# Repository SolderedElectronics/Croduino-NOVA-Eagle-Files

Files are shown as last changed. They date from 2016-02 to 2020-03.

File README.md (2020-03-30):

# Croduino NOVA Open Source Hardware Files
Croduino NOVA image
Buy Croduino NOVA [here](https://e-radionica.com/en/croduino-nova.html).

## Description and details
Croduino NOVA is microcontroller board capable of connecting to WiFi Internet network, made in Croatia(EU). It is based on very popular ESP8266 which is struggle to use standalone. With NOVA, just plug the board into USB port and start programming your next Internet-connected project(IoT)! Besides that, the board fits perfectly into a breadboard so prototyping is even more simple. Connecting the physical world to internet was never easier.

The braing of NOVA is ESP8266 produced by Espressif. It comes with complete WiFi(client and server side) and integrated TCP/IP stack which supports DNS. The most important thing - it is programmable from Arduino, there is even no need to manually reset the board due to auto-reset circuit onboard. It works at 80MHz frequency, has 1MB of flash for your code(of which 0.8MB available to you) and 82kB of RAM memory(of which 49kB available to you). NOVA also supports I2C, SPI and serial communication, there is 9 GPIO for you of which all support PWM and 1 analog input. Additionally, there is onboard: CP2102 USB to UART bridge (used for USB communication), 3.3V voltage regulator, 4 LEDs, it has FCC and CE certificate etc. In detail:

- ESP8266 in ESP-12 package
- 80MHz, 1MB flash, 82kB RAM
- programmable from Arduina!
- 9 GPIO pins of which all support PWM
- 1 analog input(ADC), max. voltage 1V i 5V
- I2C, SPI, serial communication
- CP2102 USB to UART bridge with micro USB connector
- 3.3V voltage regulator
- LEDs: power, tx, rx, GPIO13
- automatical hardware reset before upload of code
- two pushbuttons: reset i GPIO0
- comes with micro USB cable
- FCC i CE certificates for ESP-12

ESP8266 on-board is loaded with default bootloader.

## Repository content
This repo contains Cadsoft Eagle .sch and .brd files for the board. It also contains schematic in .pdf created from .sch Eagle file. 
Files have been arranged into folders for navigating between different versions of board. 
Tip: layer 200 shows top silkscreen and layer 208 is the bottom silkscreen. tParts and bParts layers are not used.

## Docs
- [Croduino NOVA product page](https://e-radionica.com/en/croduino-nova.html)

## Board versions
- v1.0 - inital published version 
- v1.1 - there was error near GPIO1 pushbutton in which GPIO0 was always directly connected to gnd. Fixed now. Silkscreen text is also a bit bigger and more readable.
- v1.2 - slight redesign, board longer 5mm and wider 2.54mm, added battery charger, changed LDO, parts rearranged. 

## License info
This product is [Open Source Hardware](https://en.wikipedia.org/wiki/Open-source_hardware), yay! Feel free to use it for any purpose you wish, but if you are ever in [Osijek, Croatia](https://goo.gl/maps/tEC2jWnBXJQpk9RJ7), you owe us a beer.

For any tech questions, please write on our [forum](http://forum.e-radionica.com/en/). If you find an Issue, please open one at GitHub. If you can improve our product, fork us.

e-radionica.com logo (https://e-radionica.com)

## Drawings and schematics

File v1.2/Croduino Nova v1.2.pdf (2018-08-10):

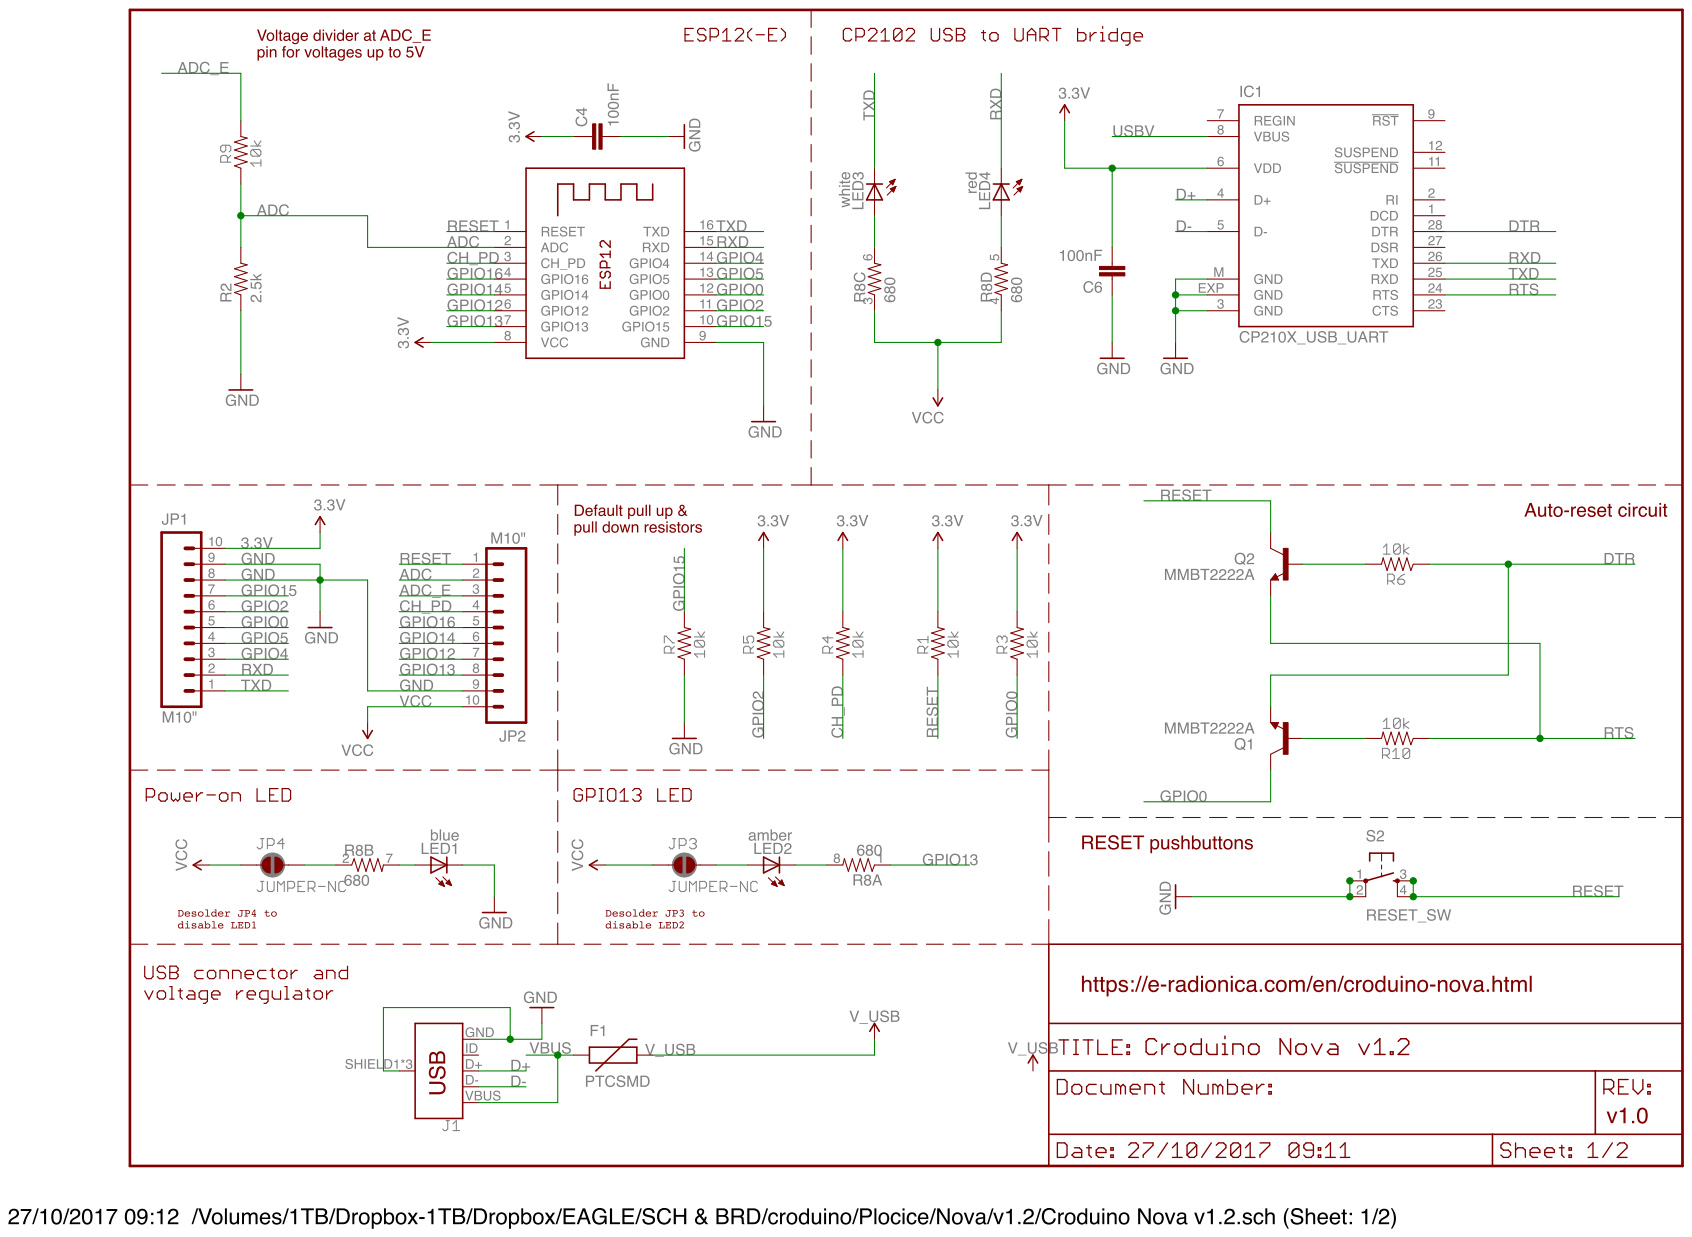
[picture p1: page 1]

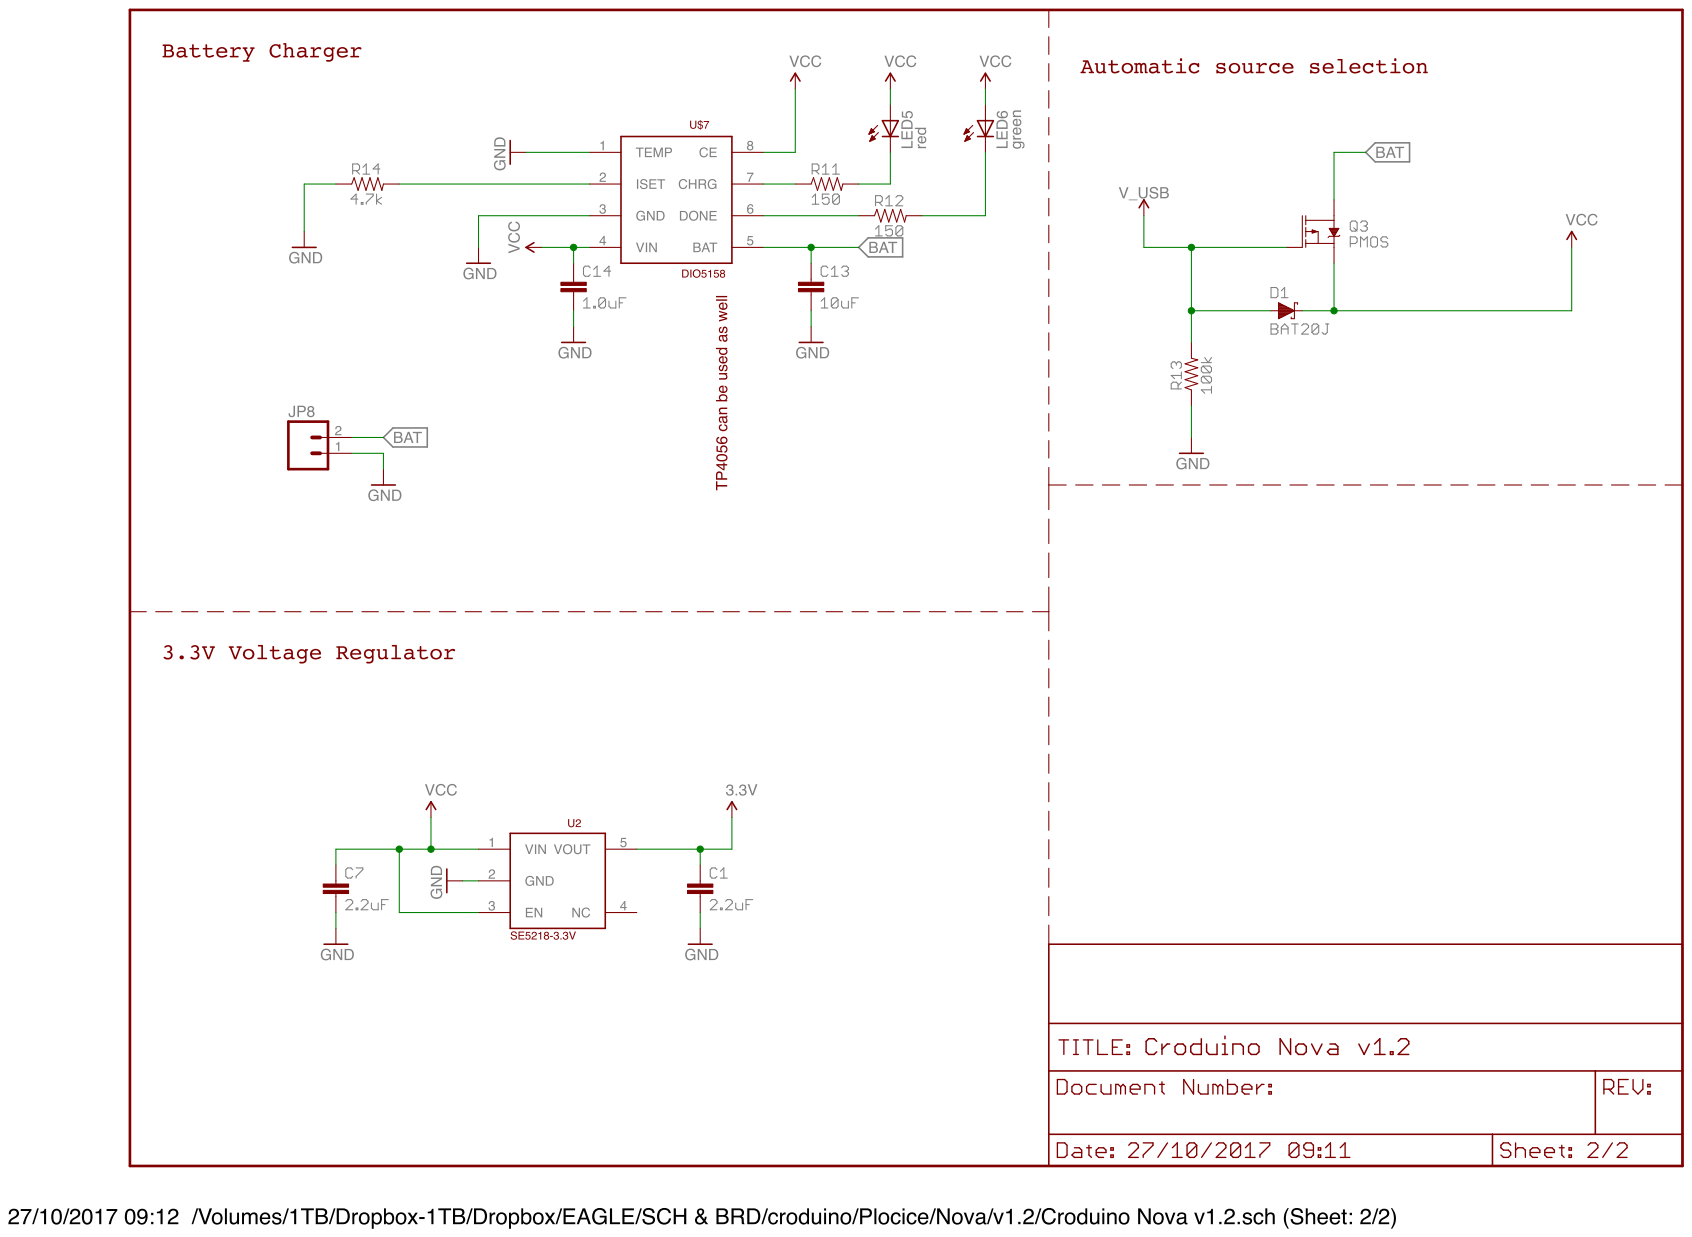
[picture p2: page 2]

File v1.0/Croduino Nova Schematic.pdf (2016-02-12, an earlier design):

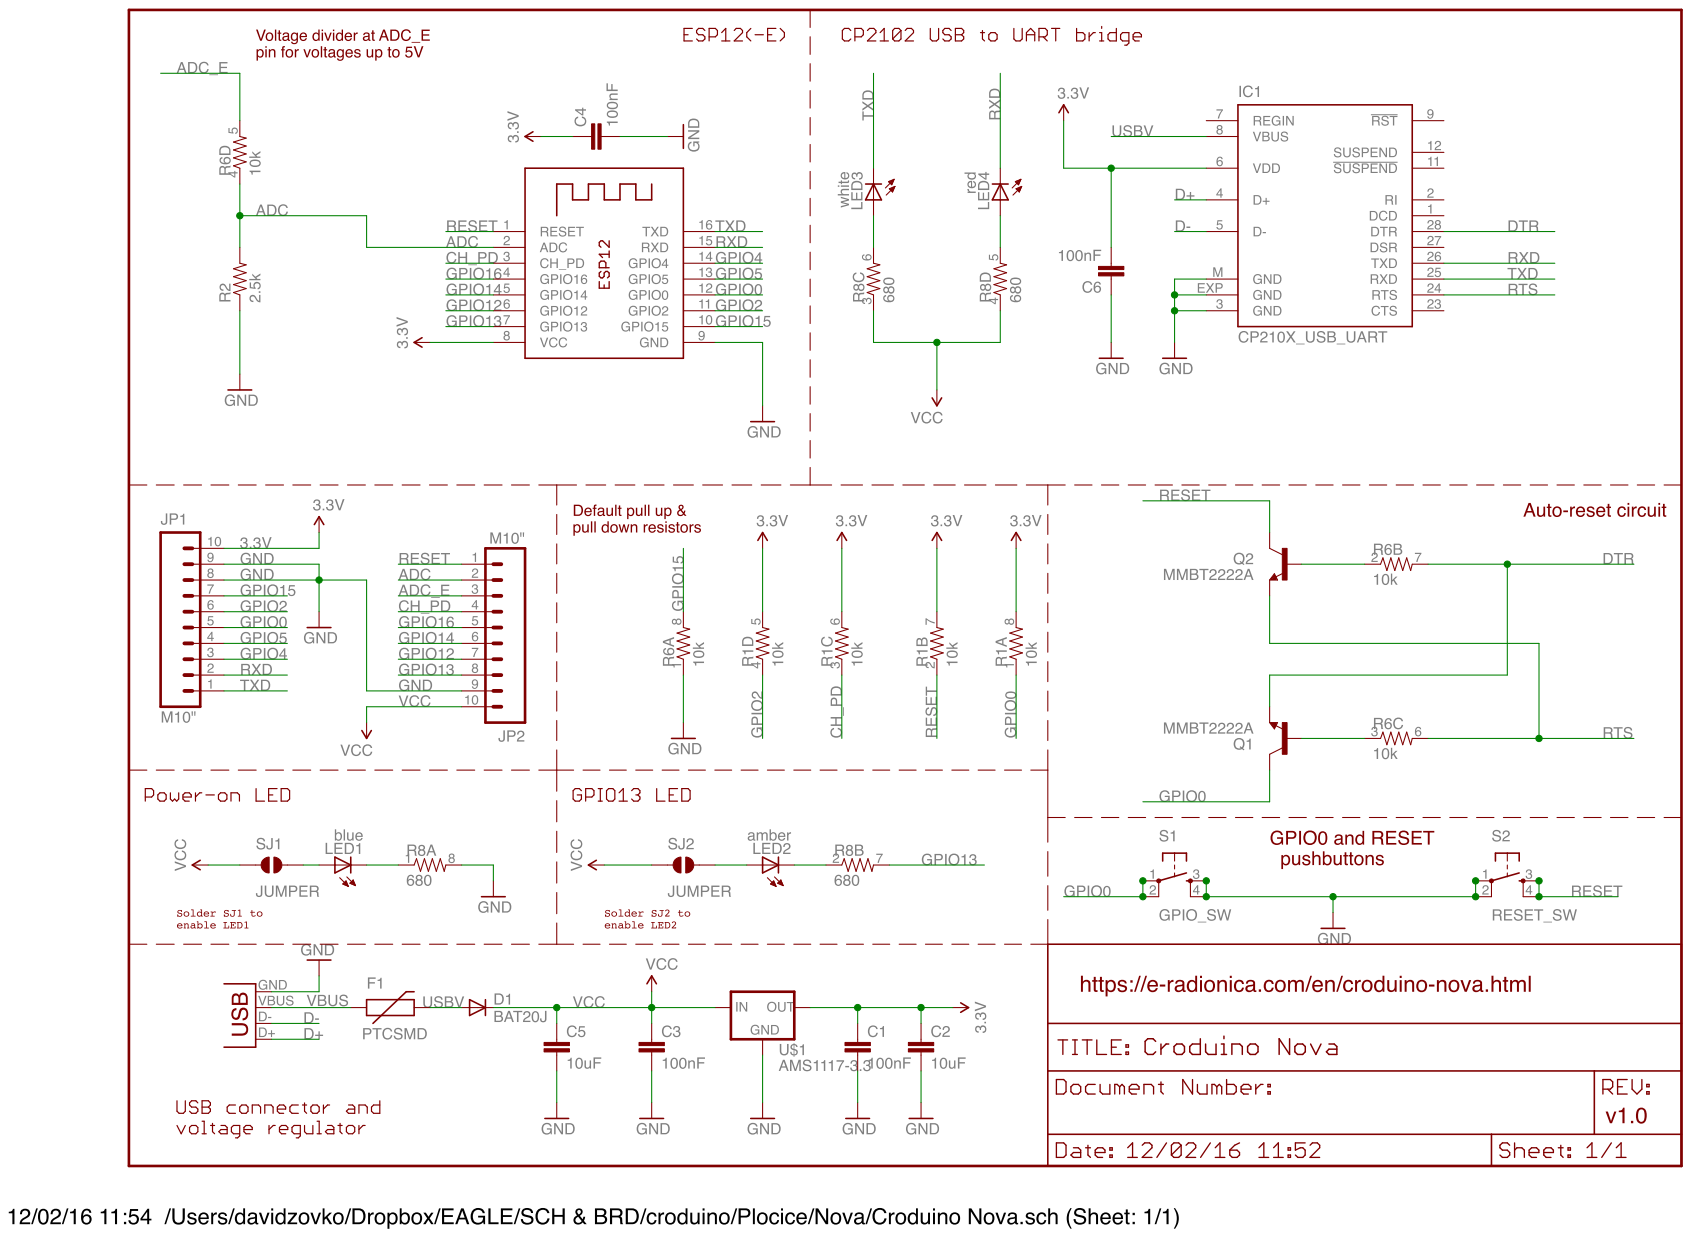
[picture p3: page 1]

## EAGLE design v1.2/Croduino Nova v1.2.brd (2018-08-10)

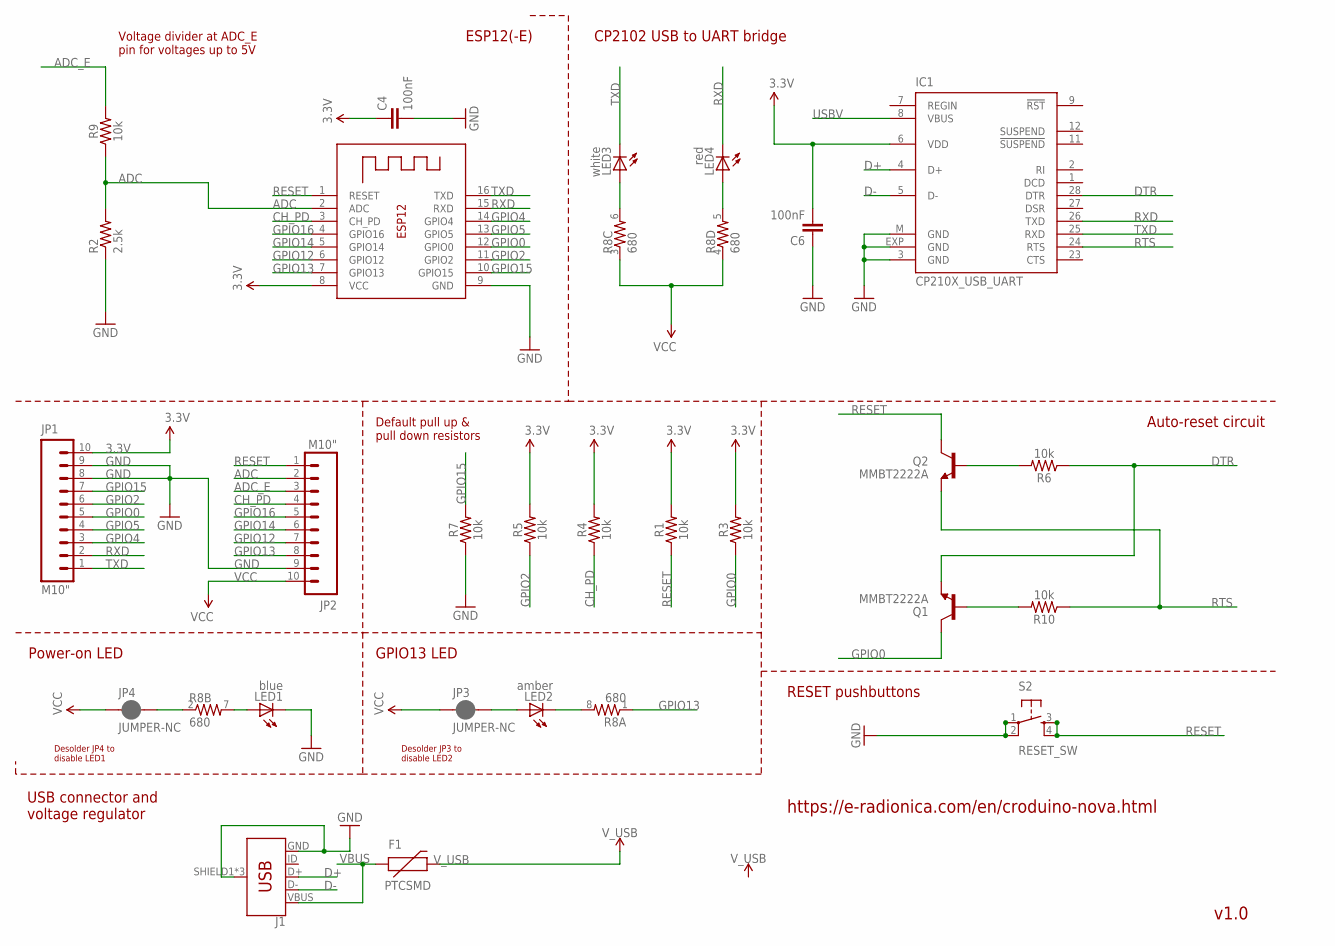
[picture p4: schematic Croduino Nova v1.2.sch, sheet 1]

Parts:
C4, C6: 100nF; 0603-CAP
F1: PTCSMD; PTC-1206
IC1: CP210X_USB_UART; MLP28
J1: USB_MICRO-BREDUCED_PASTE; USB-B-MICRO-SMD_RED_PASTE
JP1, JP2: M10"; 1X10
JP3, JP4: JUMPER-NC; SMT-JUMPER_2_NC_PASTE_NO-SILK
LED1: blue; CHIP-LED0805
LED2: amber; CHIP-LED0805
LED3: white; CHIP-LED0805
LED4: red; CHIP-LED0805
Q1, Q2: MMBT2222A; SOT23-3
R1, R3, R4, R5, R6, R7, R9, R10: 10k; 0603
R2: 2.5k; 0603-RES
R8: 680; 0603-ARV
S2: RESET_SW; TACTILE_SWITCH_SMD
X1: ESP8266-12; ESP-12

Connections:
3.3V: C4.1, C6.2, IC1.6 (VDD), JP1.10, R1.2, R3.2, R4.2, R5.2, X1.8 (VCC); also elsewhere on the board
ADC: JP2.2, R2.2, R9.1, X1.2 (ADC)
ADC_E: JP2.3, R9.2
CH_PD: JP2.4, R4.1, X1.3 (CH_PD)
D+: IC1.4 (D+), J1.D+
D-: IC1.5 (D-), J1.D-
DTR: IC1.28 (DTR), Q1.2 (E), R6.1
GND: C4.2, C6.1, IC1.3 (GND), IC1.EXP (GND), IC1.M (GND), J1.GND, J1.SHIELD1 (SHIELD), J1.SHIELD2 (SHIELD), J1.SHIELD3 (SHIELD), JP1.8, JP1.9, JP2.9, LED1.C, R2.1, R7.1, S2.1, S2.2, X1.9 (GND); also elsewhere on the board
GPIO0: JP1.5, Q1.3 (C), R3.1, X1.12 (GPIO0)
GPIO2: JP1.6, R5.1, X1.11 (GPIO2)
GPIO4: JP1.3, X1.14 (GPIO4)
GPIO5: JP1.4, X1.13 (GPIO5)
GPIO12: JP2.7, X1.6 (GPIO12)
GPIO13: JP2.8, R8.1, X1.7 (GPIO13)
GPIO14: JP2.6, X1.5 (GPIO14)
GPIO15: JP1.7, R7.2, X1.10 (GPIO15)
GPIO16: JP2.5, X1.4 (GPIO16)
unnamed: LED3.A, R8.6 (2)
unnamed: JP4.2, R8.2 (1)
unnamed: LED1.A, R8.7 (2)
unnamed: LED4.A, R8.5 (2)
unnamed: LED2.C, R8.8 (2)
unnamed: JP3.2, LED2.A
unnamed: Q1.1 (B), R10.2
unnamed: Q2.1 (B), R6.2
RESET: JP2.1, Q2.3 (C), R1.1, S2.3, S2.4, X1.1 (RESET)
RTS: IC1.24 (RTS), Q2.2 (E), R10.1
RXD: IC1.26 (TXD), JP1.2, LED4.C, X1.15 (RXD)
TXD: IC1.25 (RXD), JP1.1, LED3.C, X1.16 (TXD)
USBV: IC1.8 (VBUS)
VBUS: F1.1, J1.VBUS
VCC: JP2.10, JP3.1, JP4.1, R8.3 (1), R8.4 (1); also elsewhere on the board
V_USB: F1.2; also elsewhere on the board

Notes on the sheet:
USB connector and voltage regulator
Power-on LED
GPIO13 LED
Desolder JP4 to disable LED1
Desolder JP3 to disable LED2
ESP12(-E)
CP2102 USB to UART bridge
Voltage divider at ADC_E pin for voltages up to 5V
Default pull up & pull down resistors
Auto-reset circuit
RESET pushbuttons
https://e-radionica.com/en/croduino-nova.html
v1.0

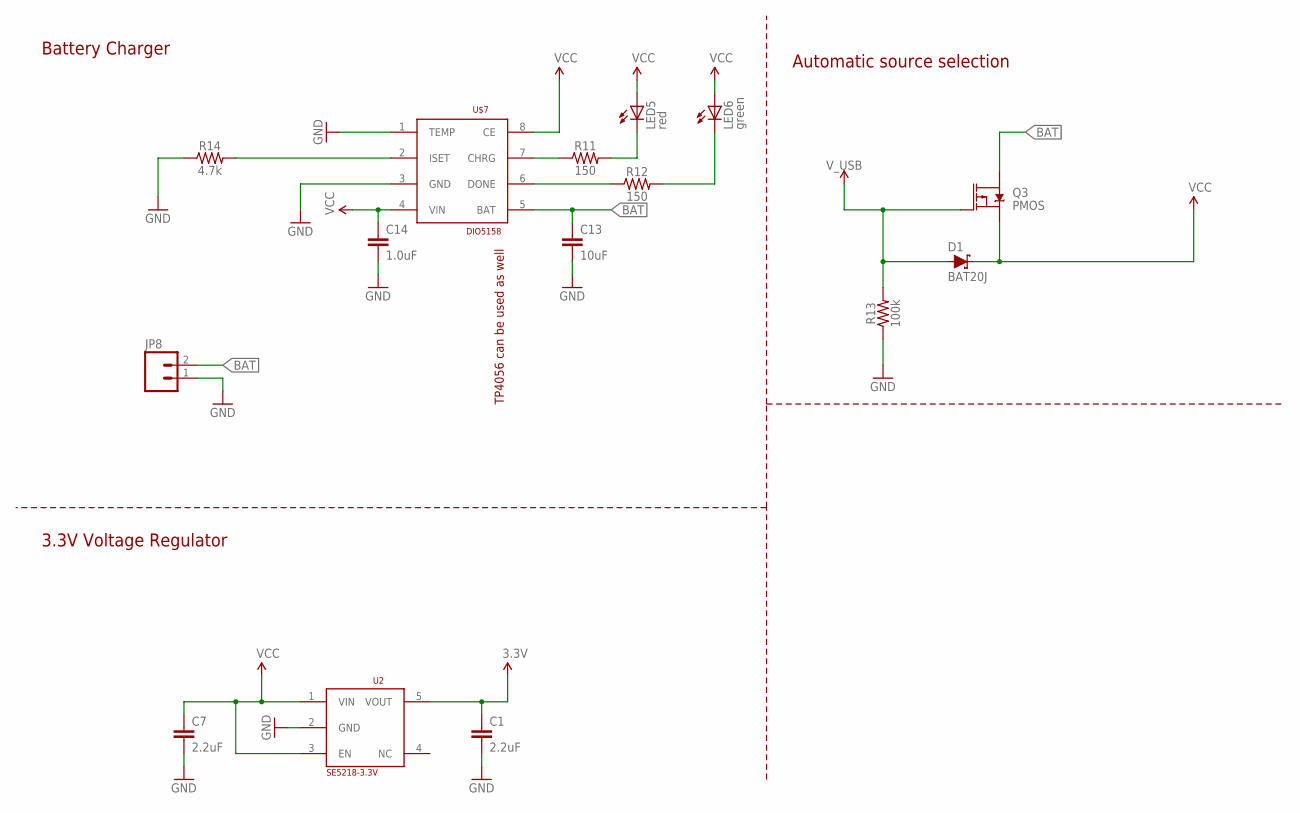
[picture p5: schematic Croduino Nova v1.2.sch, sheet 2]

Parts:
C1, C7: 2.2uF; 0603
C13: 10uF; 1206
C14: 1.0uF; 0603
D1: BAT20J; SOD-323
JP8: M02-JST-2MM-SMT; JST-2-SMD
LED5: red; CHIP-LED0805
LED6: green; CHIP-LED0805
Q3: PMOS; SOT23-3
R11, R12: 150; 0603
R13: 100k; 0603
R14: 4.7k; 0603
U2: SE5218-3.3V; SOT23-5
U$7: DIO5158; SOIC-8

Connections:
3.3V: C1.1, U2.5 (VOUT); also elsewhere on the board
BAT: C13.1, JP8.2, Q3.3 (D), U$7.5 (BAT)
CHRG: R11.1, U$7.7 (CHRG)
DONE: R12.1, U$7.6 (DONE)
GND: C1.2, C7.2, C13.2, C14.2, JP8.1, R13.1, R14.1, U2.2 (GND), U$7.1 (TEMP), U$7.3 (GND); also elsewhere on the board
ISET: R14.2, U$7.2 (ISET)
LED1: LED5.C, R11.2
LED2: LED6.C, R12.2
VCC: C7.1, C14.1, D1.C, LED5.A, LED6.A, Q3.2 (S), U2.1 (VIN), U2.3 (EN), U$7.4 (VIN), U$7.8 (CE); also elsewhere on the board
V_USB: D1.A, Q3.1 (G), R13.2; also elsewhere on the board

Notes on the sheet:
TP4056 can be used as well
3.3V Voltage Regulator
Battery Charger
Automatic source selection

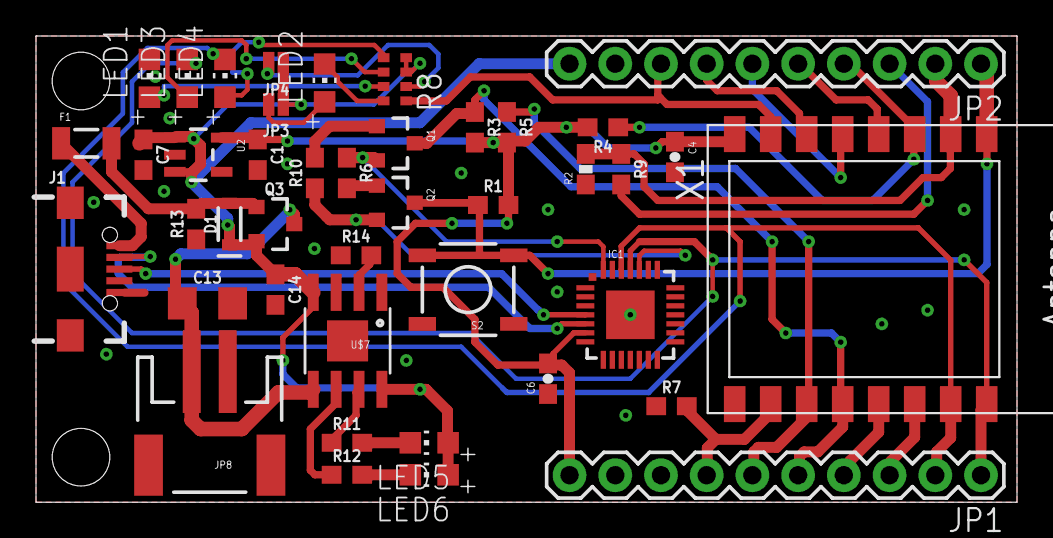
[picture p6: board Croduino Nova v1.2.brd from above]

Board: 2 copper layers, 54.5 x 25.9 mm, 48 parts (0 on the bottom side), 38 nets.

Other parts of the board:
U$1: LOGO-3MM
U$2: CRODUINO_NOVA
U$3: OSH-3MM
U$4: E-R.IO-6MM
U$5: MADE-IN-CROATIA-10MM
U$6: E-R.IO-BACK-6MM

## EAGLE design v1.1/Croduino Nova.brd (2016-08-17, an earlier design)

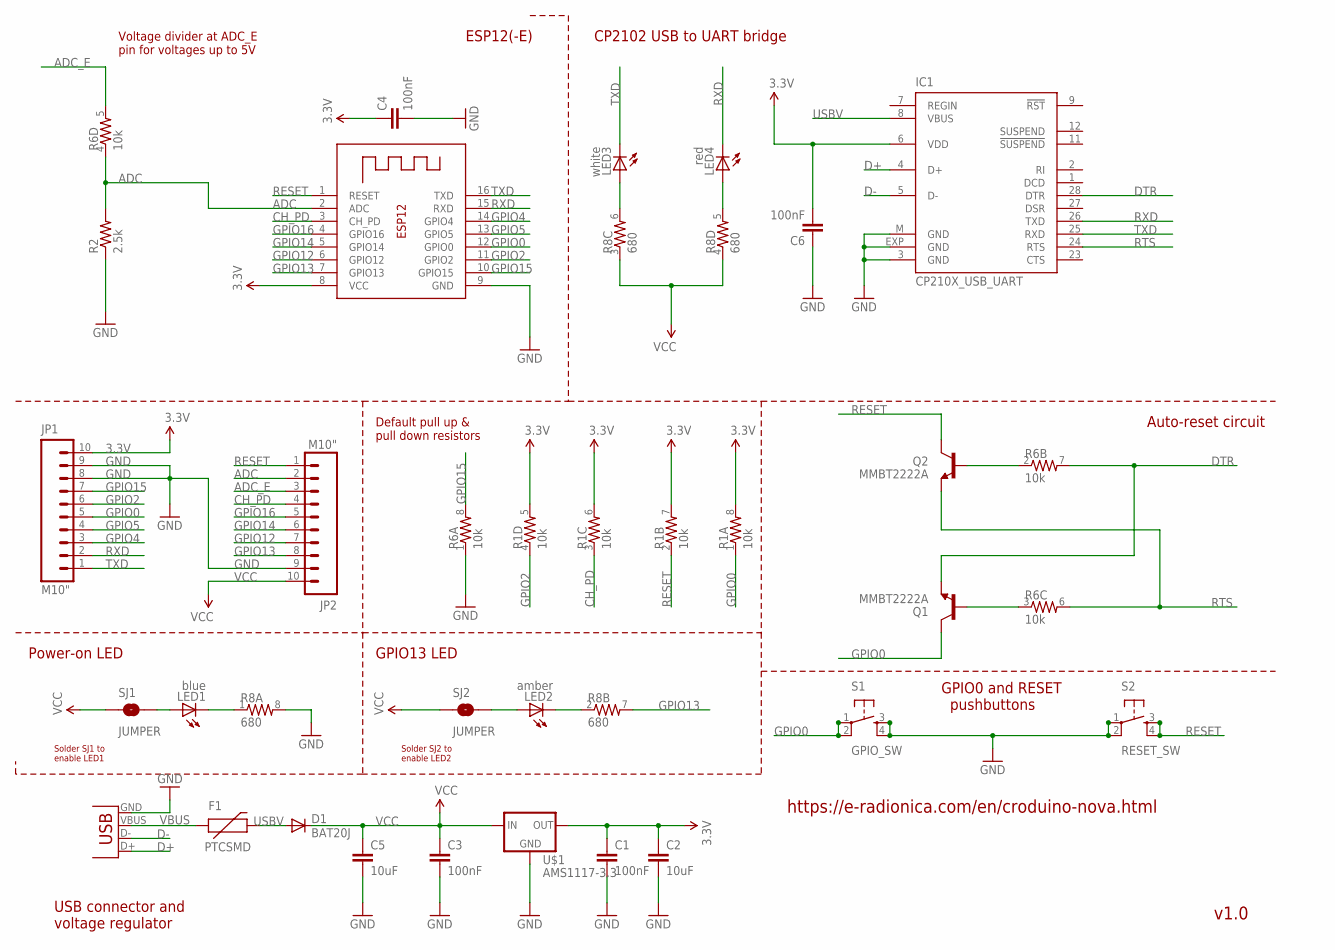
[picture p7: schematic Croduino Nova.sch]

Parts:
C1, C3, C4, C6: 100nF; 0603-CAP
C2, C5: 10uF; 1206
D1: BAT20J; SOD-323
F1: PTCSMD; PTC-1206
IC1: CP210X_USB_UART; MLP28
JP1, JP2: M10"; 1X10
LED1: blue; CHIP-LED0805
LED2: amber; CHIP-LED0805
LED3: white; CHIP-LED0805
LED4: red; CHIP-LED0805
Q1, Q2: MMBT2222A; SOT23-3
R1, R6: 10k; 0603-ARV
R2: 2.5k; 0603-RES
R8: 680; 0603-ARV
S1: GPIO_SW; TACTILE_SWITCH_SMD
S2: RESET_SW; TACTILE_SWITCH_SMD
SJ1, SJ2: JUMPER; SJ_2S
U$1: AMS1117-3.3; SOT223
X1: ESP8266-12; ESP-12
X2: USB-MICROB

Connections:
3.3V: C1.1, C2.1, C4.1, C6.2, IC1.6 (VDD), JP1.10, R1.5 (2), R1.6 (2), R1.7 (2), R1.8 (2), U$1.4 (OUT), X1.8 (VCC)
ADC: JP2.2, R2.2, R6.4 (1), X1.2 (ADC)
ADC_E: JP2.3, R6.5 (2)
CH_PD: JP2.4, R1.3 (1), X1.3 (CH_PD)
D+: IC1.4 (D+), X2.D+
D-: IC1.5 (D-), X2.D-
DTR: IC1.28 (DTR), Q1.2 (E), R6.7 (2)
GND: C1.2, C2.2, C3.2, C4.2, C5.2, C6.1, IC1.3 (GND), IC1.EXP (GND), IC1.M (GND), JP1.8, JP1.9, JP2.9, R2.1, R6.1, R8.8 (2), S1.3, S1.4, S2.1, S2.2, U$1.1 (ADJ), X1.9 (GND), X2.GND
GPIO0: JP1.5, Q1.3 (C), R1.1, S1.1, S1.2, X1.12 (GPIO0)
GPIO2: JP1.6, R1.4 (1), X1.11 (GPIO2)
GPIO4: JP1.3, X1.14 (GPIO4)
GPIO5: JP1.4, X1.13 (GPIO5)
GPIO12: JP2.7, X1.6 (GPIO12)
GPIO13: JP2.8, R8.7 (2), X1.7 (GPIO13)
GPIO14: JP2.6, X1.5 (GPIO14)
GPIO15: JP1.7, R6.8 (2), X1.10 (GPIO15)
GPIO16: JP2.5, X1.4 (GPIO16)
unnamed: LED3.A, R8.6 (2)
unnamed: LED1.A, SJ1.2
unnamed: LED1.C, R8.1
unnamed: LED4.A, R8.5 (2)
unnamed: LED2.A, SJ2.2
unnamed: LED2.C, R8.2 (1)
unnamed: Q1.1 (B), R6.3 (1)
unnamed: Q2.1 (B), R6.2 (1)
RESET: JP2.1, Q2.3 (C), R1.2 (1), S2.3, S2.4, X1.1 (RESET)
RTS: IC1.24 (RTS), Q2.2 (E), R6.6 (2)
RXD: IC1.26 (TXD), JP1.2, LED4.C, X1.15 (RXD)
TXD: IC1.25 (RXD), JP1.1, LED3.C, X1.16 (TXD)
USBV: D1.2 (A), F1.2, IC1.8 (VBUS)
VBUS: F1.1, X2.VBUS
VCC: C3.1, C5.1, D1.1 (C), JP2.10, R8.3 (1), R8.4 (1), SJ1.1, SJ2.1, U$1.3 (IN)

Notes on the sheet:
USB connector and voltage regulator
Power-on LED
GPIO13 LED
Solder SJ1 to enable LED1
Solder SJ2 to enable LED2
ESP12(-E)
CP2102 USB to UART bridge
Voltage divider at ADC_E pin for voltages up to 5V
Default pull up & pull down resistors
Auto-reset circuit
GPIO0 and RESET pushbuttons
https://e-radionica.com/en/croduino-nova.html
v1.0

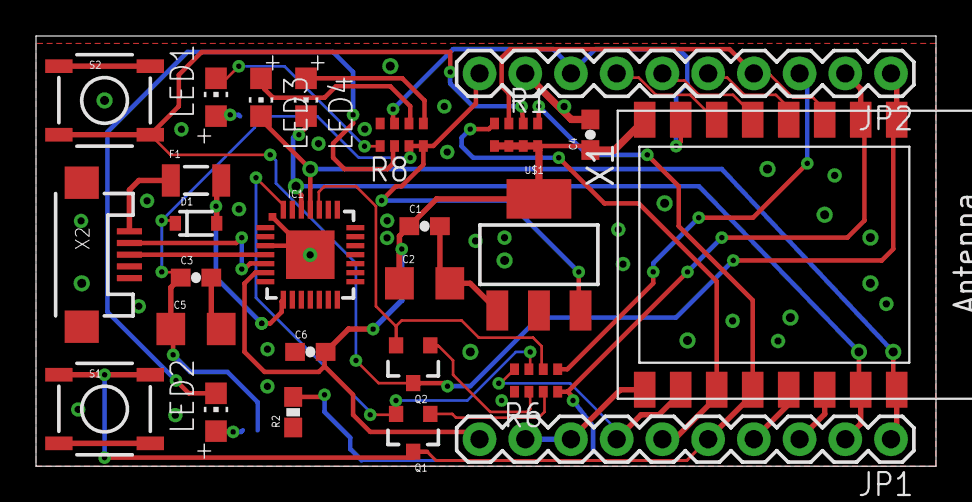
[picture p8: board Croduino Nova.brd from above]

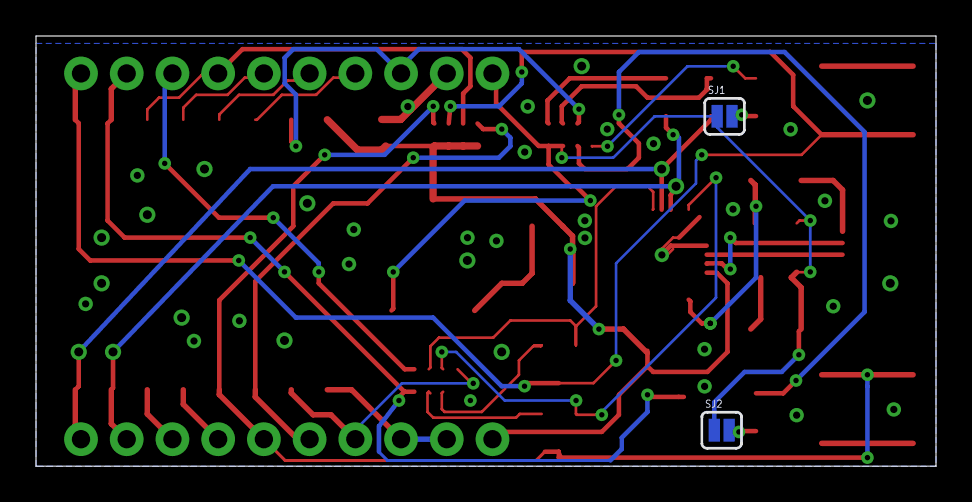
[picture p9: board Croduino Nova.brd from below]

Board: 2 copper layers, 50.0 x 23.9 mm, 31 parts (2 on the bottom side), 32 nets.

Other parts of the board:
U$2: CRODUINO_NOVA
U$3: NOVI_LOGO-4MM
U$4: OSH3MM

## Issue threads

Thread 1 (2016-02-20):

Ne radi ispravno !

mozgy, 2016-02-20:
Pozdrav,

primih jedan primjerak (Chip ID: 495350) ali ne radi ispravno, cijelo vrijeme je u bootloader modu.

davidzovko, 2016-02-25:
Kratki spoj ispod GPIO_SW - spojen GPIO0 s groundom pa pločica automatski odlazi u boot mode. Ispravljeno na v1.1.

Fix za ovu verziju je prerezati trace prikazan na slici. Nakon toga sve radi odlično.
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

Closed 2022-11-03.

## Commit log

2016-02-12 Inital upload of files
    [Croduino Nova.brd, Croduino Nova.sch]
2016-08-17 Added v1.1
    v1.1 of Eagle files was added. There small change in PCB design.
    [Croduino Nova.brd, Croduino Nova.sch]
2017-10-19 Added v1.2 version of the board
    [Croduino Nova v1.2.brd, Croduino Nova v1.2.sch]
2018-08-10 added v1.2 version
    [Croduino Nova v1.2.brd, Croduino Nova v1.2.sch]

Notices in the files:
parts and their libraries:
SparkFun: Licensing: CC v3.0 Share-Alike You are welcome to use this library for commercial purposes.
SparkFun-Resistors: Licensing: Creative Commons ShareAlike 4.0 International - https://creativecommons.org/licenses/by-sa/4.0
